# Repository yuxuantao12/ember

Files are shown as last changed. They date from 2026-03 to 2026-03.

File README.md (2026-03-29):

# EMBER — Emergency Monitor for Building Evacuation and Rescue

> Real-time firefighter tracking system for incident commanders. Built for a 24-hour hackathon.





## What is EMBER?

EMBER tracks firefighters inside buildings in real time. Each firefighter wears a sensor node that broadcasts their GPS position and heading via NRF24L01 radio to a base station outside the building. The base station forwards data over USB serial to a laptop running a browser-based dashboard that overlays firefighter positions on an uploaded floor plan.

```
┌─────────────┐     ┌─────────────┐
│ Wearable A  │     │ Wearable B  │
│ Nano+GPS+IMU│     │ Nano+GPS+IMU│
└──────┬──────┘     └──────┬──────┘
       │  2.4 GHz Radio    │
       └────────┬──────────┘
                │
       ┌────────┴────────┐
       │  Base Station   │
       │  Nano+NRF24L01  │
       └────────┬────────┘
                │ USB Serial
       ┌────────┴────────┐
       │ Laptop Dashboard│
       │ Chrome/Edge     │
       └─────────────────┘
```

## Project Structure

```
ember/
├── dashboard/              # Browser-based tracking dashboard (CS person)
│   ├── index.html          # Main entry point — open in Chrome
│   ├── css/
│   │   └── styles.css      # All styles — dark fire-themed UI
│   └── js/
│       ├── app.js           # Init, state management, UI updates
│       ├── serial.js        # Web Serial API connection layer
│       ├── canvas.js        # Floor plan rendering + firefighter markers
│       ├── calibration.js   # GPS-to-pixel coordinate mapping
│       └── mock.js          # Fake data generator for development
│
├── firmware/               # Arduino sketches (CE person)
│   ├── wearable_node/      # Wearable firefighter node firmware
│   │   └── wearable_node.ino
│   ├── base_station/       # Base station receiver firmware
│   │   └── base_station.ino
│   └── esp01_wifi_bonus/   # BONUS: ESP-01 WiFi dashboard
│       └── esp01_wifi_bonus.ino
│
├── hardware/               # Wiring diagrams and pin maps (EE person)
│   └── PIN_MAP.md          # Complete pin assignments for all units
│
├── docs/                   # Build guide and documentation
│   └── EMBER_Nano_Build_Guide.docx
│
└── README.md               # This file
```

## Hardware Requirements

| Component | Qty | Purpose |
|---|-----|---|
| Arduino Nano | 3 | Main controller for all units |
| NRF24L01 (standard) | 3 | 2.4 GHz radio (1 per Nano) |
| IMU (MPU6050/9250) | 2 | Heading/orientation (wearables only) |
| GPS (NEO-6M) | 2 | Position tracking (wearables only) |
| Active Buzzer | 3 | Audible alerts (1 per unit) |
| 10µF Capacitor | 3 | NRF24L01 power stabilization |
| ESP-01 (ESP8266) | 1 | BONUS: WiFi phone dashboard |

## Quick Start

### Dashboard (no hardware needed)
1. Open `dashboard/index.html` in **Chrome** or **Edge**
2. Click **Mock Data** to simulate two firefighters
3. Click **Upload Floor Plan** to load a building image
4. Click **Calibrate** to set GPS-to-pixel mapping

### With Hardware
1. Flash `firmware/wearable_node/wearable_node.ino` to wearable Nanos
2. Flash `firmware/base_station/base_station.ino` to base station Nano
3. Connect base station to laptop via USB
4. Open `dashboard/index.html` in Chrome
5. Click **Connect** and select the Nano's serial port

## Pin Map (Arduino Nano)

| Pin | Wearable | Base Station |
|-----|---|---|
| D3 | GPS TX (SoftwareSerial RX) | ESP-01 RX (bonus) |
| D4 | GPS RX (SoftwareSerial TX) | — |
| D6 | Buzzer + | Buzzer + |
| D9 | NRF24L01 CE | NRF24L01 CE |
| D10 | NRF24L01 CSN | NRF24L01 CSN |
| D11 | NRF24L01 MOSI | NRF24L01 MOSI |
| D12 | NRF24L01 MISO | NRF24L01 MISO |
| D13 | NRF24L01 SCK | NRF24L01 SCK |
| A4 | IMU SDA | — |
| A5 | IMU SCL | — |
| 3.3V | NRF24L01 VCC | NRF24L01 VCC |
| 5V | IMU VCC, GPS VCC | — |

## Serial Protocol

Base station sends JSON lines at 115200 baud:
```json
{"id":1,"lat":29.6516,"lng":-82.3248,"heading":135.2,"fix":1,"alert":0,"batt":87,"stat":0}
```

Dashboard can send commands back:
```
BUZZ:1    // Alert firefighter 1
BUZZ:2    // Alert firefighter 2
```

## Team Roles

- **EE** — Soldering, wiring, 3D enclosures, hardware debugging
- **CE** — All Arduino firmware, radio config, serial protocols
- **CS** — Browser dashboard, Web Serial API, UI/UX

## Browser Support

The dashboard uses the [Web Serial API](https://developer.mozilla.org/en-US/docs/Web/API/Web_Serial_API) which is supported in:
- ✅ Chrome 89+
- ✅ Edge 89+
- ❌ Firefox (not supported)
- ❌ Safari (not supported)

## Google Maps API Key

The private API key has been omitted. Please request an API key at https://console.cloud.google.com/ for map function. 

## License

MIT

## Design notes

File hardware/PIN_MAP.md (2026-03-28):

# EMBER Hardware Pin Map — Arduino Nano

## Wearable Node (×2)

| Nano Pin | Connected To | Protocol | Wire Color (suggested) |
|---|---|---|---|
| D0 (RX)  | USB (reserved) | Hardware UART | — do not connect — |
| D1 (TX)  | USB (reserved) | Hardware UART | — do not connect — |
| D2 | *unassigned* | — | |
| D3 | GPS TX | SoftwareSerial RX | White |
| D4 | GPS RX | SoftwareSerial TX | Gray |
| D5 | *unassigned* | — | |
| D6 | Buzzer (+) | Digital Output | Yellow |
| D7 | *unassigned* | — | |
| D8 | *unassigned* | — | |
| D9 | NRF24L01 CE | Digital Output | Orange |
| D10 | NRF24L01 CSN | SPI SS | Brown |
| D11 | NRF24L01 MOSI | SPI MOSI | Green |
| D12 | NRF24L01 MISO | SPI MISO | Blue |
| D13 | NRF24L01 SCK | SPI SCK | Purple |
| A0–A3 | *unassigned* | — | |
| A4 | IMU SDA | I2C Data | White (twisted pair) |
| A5 | IMU SCL | I2C Clock | Yellow (twisted pair)  |
| A6–A7 | *unassigned* | Analog only | |
| 5V | IMU VCC, GPS VCC | Power | Red |
| 3.3V | NRF24L01 VCC + Cap | Power | Red (3.3V rail) |
| GND | All GNDs + Cap − | Ground | Black |

**Critical:** 10µF capacitor across NRF24L01 VCC and GND, as close to the module as possible.

---

## Base Station (×1)

| Nano Pin | Connected To | Protocol | Notes |
|---|---|---|---|
| D0 (TX)  | USB → Laptop | Hardware UART | JSON data at 115200 |
| D1 (RX)  | USB ← Laptop | Hardware UART | BUZZ commands from dashboard |
| D3 | ESP-01 RX (BONUS)  | SoftwareSerial TX | Via voltage divider (1K+2K) |
| D6 | Buzzer (+) | Digital Output | |
| D9 | NRF24L01 CE | Digital Output | |
| D10 | NRF24L01 CSN | SPI SS | |
| D11 | NRF24L01 MOSI | SPI MOSI | |
| D12 | NRF24L01 MISO | SPI MISO | |
| D13 | NRF24L01 SCK | SPI SCK | |
| 3.3V | NRF24L01 VCC + Cap (+ ESP-01 VCC if bonus) | Power | |
| GND | All GNDs | Ground | |

---

## ESP-01 Bonus (base station only)

| ESP-01 Pin | Connected To | Notes |
|---|---|---|
| VCC | Nano 3.3V | 3.3V ONLY |
| GND | Nano GND | |
| RX | Nano D3 via voltage divider | 1K from D3 → ESP RX, 2K from ESP RX → GND |
| TX | Not connected | |
| CH_PD (EN) | 3.3V via 10K pullup | Must be HIGH to run |
| GPIO0 | 3.3V via 10K pullup | HIGH = run mode, LOW = flash mode  |
| GPIO2 | Not connected | |
| RST | 3.3V via 10K pullup | Prevent accidental resets |

---

## NRF24L01 Module Pinout (8 pins, top view)

```
         ┌─────────────┐
    GND  │ 1    2      │  VCC (3.3V!)
     CE  │ 3    4      │  CSN
    SCK  │ 5    6      │  MOSI
   MISO  │ 7    8      │  IRQ (not used)
         └─────────────┘
```

**Pin 2 (VCC) = 3.3V ONLY. Connecting to 5V will permanently destroy the module.**

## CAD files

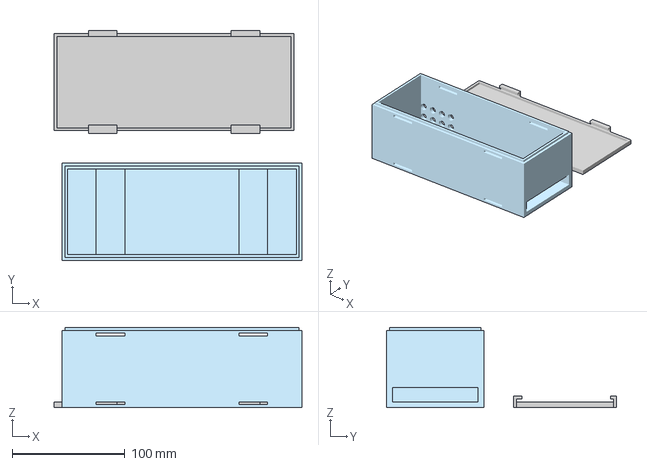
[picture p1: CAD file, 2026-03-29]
Design.3mf
220.4 x 204.2 x 71.1 mm

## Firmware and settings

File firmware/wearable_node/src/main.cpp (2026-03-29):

#include <SPI.h>
#include <RF24.h>
#include <TinyGPSPlus.h>
#include <SoftwareSerial.h>
#include <Wire.h>
#include <avr/wdt.h>

// Unique ID for this specific unit so the base station knows who is talking
#define NODE_ID      1
#define RF_CHANNEL   108
#define TX_INTERVAL  500
#define BUZZER_PIN   6
#define GPS_RX_PIN   3
#define GPS_TX_PIN   4
#define NRF_CE_PIN   9
#define NRF_CSN_PIN  10
#define IMU_ADDR     0x68

// Button pins
#define BTN_SURVIVOR   2   // "Survivor Here"
#define BTN_NO_SURVIVOR 5  // "No Survivor"
#define BTN_DANGER     7   // "Dangerous Area"

// Alert enums
#define ALERT_NONE        0
#define ALERT_STATIONARY  1  
#define ALERT_SURVIVOR    2   // survivor found here
#define ALERT_NO_SURVIVOR 3   // no survivor here
#define ALERT_DANGER      4   // dangerous area

const byte pipeAddr[] = "EMBB1";

//Base/Node struct
struct __attribute__((packed)) SensorPacket {
  uint8_t  nodeId;
  float    latitude;
  float    longitude;
  float    heading;
  uint8_t  gpsFix;
  uint8_t  alertFlag;
  uint8_t  batteryPct;
  uint16_t stationaryMs;
  float    drLat;
  float    drLng;
  uint8_t  pinDrop;
};

RF24 radio(NRF_CE_PIN, NRF_CSN_PIN);
TinyGPSPlus gps;
SoftwareSerial gpsSerial(GPS_RX_PIN, GPS_TX_PIN);

SensorPacket packet;
unsigned long lastTx     = 0;
unsigned long lastMoveTime = 0;
float prevHeading        = 0;

//Dead reckoning state
float    drLat           = 0.0;   // current DR latitude
float    drLng           = 0.0;   // current DR longitude
bool     drInitialised   = false;
float    drSpeed         = 0.9;  
unsigned long lastDrUpdate = 0;

//Button debounce state
unsigned long lastBtnPress[3] = {0, 0, 0};
const uint8_t btnPins[3]      = {BTN_SURVIVOR, BTN_NO_SURVIVOR, BTN_DANGER};
const uint8_t btnAlerts[3]    = {ALERT_SURVIVOR, ALERT_NO_SURVIVOR, ALERT_DANGER};
const uint16_t DEBOUNCE_MS    = 300;

// Pending pin drop
bool    pendingPin     = false;
uint8_t pendingAlert   = ALERT_NONE;
float   pendingDrLat   = 0.0;
float   pendingDrLng   = 0.0;

float readHeading();
void  updateDeadReckoning();
void  checkButtons();
void  buzzerConfirm(uint8_t alertType);

void setup() {
  wdt_disable();
  Serial.begin(115200);
  Serial.println(F("Node A starting..."));

  // Button pins — internal pull-up, buttons connect pin to GND
  pinMode(BTN_SURVIVOR,    INPUT_PULLUP);
  pinMode(BTN_NO_SURVIVOR, INPUT_PULLUP);
  pinMode(BTN_DANGER,      INPUT_PULLUP);

  pinMode(BUZZER_PIN, OUTPUT);
  digitalWrite(BUZZER_PIN, HIGH);
  delay(150);
  digitalWrite(BUZZER_PIN, LOW);

  gpsSerial.begin(9600);

  Wire.begin();
  Wire.beginTransmission(IMU_ADDR);
  Wire.write(0x6B);
  Wire.write(0x00);
  Wire.endTransmission(true);

  if (!radio.begin()) {
    Serial.println(F("NRF FAIL"));
    while (1) {
      digitalWrite(BUZZER_PIN, HIGH); delay(200);
      digitalWrite(BUZZER_PIN, LOW);  delay(200);
    }
  }

  radio.setChannel(RF_CHANNEL);
  radio.setDataRate(RF24_250KBPS);
  radio.setPALevel(RF24_PA_MAX);
  radio.setRetries(15, 15);
  radio.setPayloadSize(sizeof(SensorPacket));
  radio.openWritingPipe(pipeAddr);
  radio.stopListening();

  Serial.println(F("Node A ready."));
  packet.nodeId = NODE_ID;
  lastMoveTime  = millis();
  lastDrUpdate  = millis();
  wdt_enable(WDTO_2S);
}

void loop() {
  wdt_reset();

  // Feed GPS
  while (gpsSerial.available() > 0) gps.encode(gpsSerial.read());

  if (gps.location.isValid()) {
    packet.latitude  = gps.location.lat();
    packet.longitude = gps.location.lng();
    packet.gpsFix    = 1;
    // Use real GPS as DR anchor
    drLat          = packet.latitude;
    drLng          = packet.longitude;
    drInitialised  = true;
  } else {
    packet.latitude  = 0.0;
    packet.longitude = 0.0;
    packet.gpsFix    = 0;
  }

  packet.heading = readHeading();
  updateDeadReckoning();
  checkButtons();

  // Stationary detection
  if (abs(packet.heading - prevHeading) > 5.0) {
    lastMoveTime = millis();
    prevHeading  = packet.heading;
  }
  packet.stationaryMs = (uint16_t)min((unsigned long)65535, millis() - lastMoveTime);

  // Alert priority: button press overrides stationary alert
  if (pendingPin) {
    packet.alertFlag  = pendingAlert;
    packet.drLat      = pendingDrLat;
    packet.drLng      = pendingDrLng;
    packet.pinDrop    = 1;
  } else {
    packet.alertFlag  = (packet.stationaryMs > 60000) ? ALERT_STATIONARY : ALERT_NONE;
    packet.drLat      = drLat;
    packet.drLng      = drLng;
    packet.pinDrop    = 0;
  }

  packet.batteryPct = 100;

  if (millis() - lastTx >= TX_INTERVAL) {
    lastTx = millis();
    bool ok = radio.write(&packet, sizeof(packet));

    // If pin drop was sent, clear it
    if (pendingPin && ok) {
      pendingPin = false;
    }

    // Serial output as JSON for the  dashboard
    Serial.print(F("{\"id\":"));    Serial.print(packet.nodeId);
    Serial.print(F(",\"lat\":"));   Serial.print(packet.latitude, 6);
    Serial.print(F(",\"lng\":"));   Serial.print(packet.longitude, 6);
    Serial.print(F(",\"heading\":")); Serial.print(packet.heading, 1);
    Serial.print(F(",\"fix\":"));   Serial.print(packet.gpsFix);
    Serial.print(F(",\"alert\":")); Serial.print(packet.alertFlag);
    Serial.print(F(",\"batt\":"));  Serial.print(packet.batteryPct);
    Serial.print(F(",\"stat\":"));  Serial.print(packet.stationaryMs);
    Serial.print(F(",\"pin\":"));   Serial.print(packet.pinDrop);
    Serial.print(F(",\"drLat\":")); Serial.print(packet.drLat, 6);
    Serial.print(F(",\"drLng\":")); Serial.print(packet.drLng, 6);
    Serial.println(F("}"));
  }
}

//Dead reckoning update
// Converts heading + speed + elapsed time into a lat/lng offset
void updateDeadReckoning() {
  if (!drInitialised) return;

  unsigned long now = millis();
  float dt = (now - lastDrUpdate) / 1000.0;
  lastDrUpdate = now;

  if (dt <= 0 || dt > 2.0) return;

  // Only advance DR if unit is not stationary
  if (packet.stationaryMs > 3000) return;

  float distMetres = drSpeed * dt;

  // Convert heading to radians
  float headRad = packet.heading * PI / 180.0;

  // 1 degree latitude ≈ 111320 metres
  float dLat = (distMetres * cos(headRad)) / 111320.0;

  // 1 degree longitude ≈ 111320 * cos(lat) metres
  float cosLat = cos(drLat * PI / 180.0);
  float dLng = (cosLat > 0.001) ? (distMetres * sin(headRad)) / (111320.0 * cosLat) : 0.0;

  drLat += dLat;
  drLng += dLng;
}

//Button check with debounce
void checkButtons() {
  for (int i = 0; i < 3; i++) {
    // Buttons are INPUT_PULLUP so LOW = pressed
    if (digitalRead(btnPins[i]) == LOW) {
      unsigned long now = millis();
      if (now - lastBtnPress[i] > DEBOUNCE_MS) {
        lastBtnPress[i] = now;

        // Capture current DR position as pin drop location
        pendingPin     = true;
        pendingAlert   = btnAlerts[i];
        pendingDrLat   = drLat;
        pendingDrLng   = drLng;

         switch (btnAlerts[i]) {
          case ALERT_SURVIVOR:    Serial.println(F(">>> BUTTON: SURVIVOR HERE <<<")); break;
          case ALERT_NO_SURVIVOR: Serial.println(F(">>> BUTTON: NO SURVIVOR <<<")); break;
          case ALERT_DANGER:      Serial.println(F(">>> BUTTON: DANGEROUS AREA <<<")); break;
        }

        buzzerConfirm(btnAlerts[i]);

        Serial.print(F("BTN: alert="));
        Serial.print(btnAlerts[i]);
        Serial.print(F(" drLat="));
        Serial.print(drLat, 6);
        Serial.print(F(" drLng="));
        Serial.println(drLng, 6);
      }
    }
  }
}


void buzzerConfirm(uint8_t alertType) {
  wdt_reset();
  delay(10);  
  switch (alertType) {
    case ALERT_SURVIVOR:
      digitalWrite(BUZZER_PIN, HIGH); delay(80);
      digitalWrite(BUZZER_PIN, LOW);  delay(60);
      digitalWrite(BUZZER_PIN, HIGH); delay(80);
      digitalWrite(BUZZER_PIN, LOW);
      break;
    case ALERT_NO_SURVIVOR:
      digitalWrite(BUZZER_PIN, HIGH); delay(150);
      digitalWrite(BUZZER_PIN, LOW);
      break;
    case ALERT_DANGER:
      for (int i = 0; i < 3; i++) {
        digitalWrite(BUZZER_PIN, HIGH); delay(60);
        digitalWrite(BUZZER_PIN, LOW);  delay(50);
      }
      break;
  }
  wdt_reset();
}

float readHeading() {
  Wire.beginTransmission(IMU_ADDR);
  Wire.write(0x47);
  Wire.endTransmission(false);
  Wire.requestFrom(IMU_ADDR, 2, true);
  int16_t gyroZ = Wire.read() << 8 | Wire.read();
  float rate = gyroZ / 131.0;

  static float yaw = 0;
  static unsigned long lastTime = 0;
  unsigned long now = millis();
  float dt = (now - lastTime) / 1000.0;
  lastTime = now;
  if (dt > 0 && dt < 1.0) yaw += rate * dt;
  yaw = fmod(yaw, 360.0);
  if (yaw < 0) yaw += 360.0;
  return yaw;
}

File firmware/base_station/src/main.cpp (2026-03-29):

#include <SPI.h>
#include <RF24.h>
#include <avr/wdt.h>

// Using channel 108 to stay clear of the noisier low-end WiFi frequencies
#define RF_CHANNEL   108
#define NRF_CE_PIN   9
#define NRF_CSN_PIN  10
#define BUZZER_PIN   6

// This struct is the "handshake" between the nodes and this base station.
// __attribute__((packed)) ensures no sneaky padding is added by the compiler,
// so the bytes align perfectly over the air.

struct __attribute__((packed)) SensorPacket {
  uint8_t  nodeId;
  float    latitude;
  float    longitude;
  float    heading;
  uint8_t  gpsFix;
  uint8_t  alertFlag;
  uint8_t  batteryPct;
  uint16_t stationaryMs;
  float    drLat;
  float    drLng;
  uint8_t  pinDrop;
};

RF24 radio(NRF_CE_PIN, NRF_CSN_PIN);

// Hardcoded addresses for our two main nodes (only one node implemented)
const byte addrA[] = "EMBB1";
const byte addrB[] = "EMBB2";

unsigned long lastPacketTime[3] = {0, 0, 0};
bool buzzerActive = false;
unsigned long buzzerOffTime = 0;

// Prototypes for the helpers below
String buildJson(SensorPacket &p);
void sendBuzzCommand(uint8_t targetId);

void setup() {
  wdt_disable();
  Serial.begin(115200);
  Serial.println(F("{\"status\":\"EMBER base station starting\"}"));

  pinMode(BUZZER_PIN, OUTPUT);
  digitalWrite(BUZZER_PIN, HIGH);
  delay(100);
  digitalWrite(BUZZER_PIN, LOW);

  if (!radio.begin()) {
    Serial.println(F("{\"error\":\"NRF HARDWARE FAIL\"}"));
    while (1) {
      digitalWrite(BUZZER_PIN, HIGH); delay(200);
      digitalWrite(BUZZER_PIN, LOW);  delay(200);
    }
  }

// Radio fine-tuning: 250KBPS gives us the best possible range
  radio.setChannel(RF_CHANNEL);
  radio.setDataRate(RF24_250KBPS);
  radio.setPALevel(RF24_PA_MAX);
  radio.setRetries(15, 15);
  radio.setPayloadSize(sizeof(SensorPacket));

// Listen for both nodes simultaneously on different pipes
  radio.openReadingPipe(1, addrA);
  radio.openReadingPipe(2, addrB);
  radio.startListening();

  Serial.println(F("{\"status\":\"Listening on EMBB1 and EMBB2\"}"));
  wdt_enable(WDTO_2S);
}

void loop() {
  wdt_reset();
  uint8_t pipeNum = 0;

// Check if any node has sent a status update
  if (radio.available(&pipeNum)) {
    SensorPacket pkt;
    radio.read(&pkt, sizeof(pkt));

// We use the pipe number as the ID to verify which node sent what
    pkt.nodeId = pipeNum;
    lastPacketTime[pkt.nodeId] = millis();
    Serial.println(buildJson(pkt));

  }

  if (Serial.available()) {
    String cmd = Serial.readStringUntil('\n');
    cmd.trim();
    if (cmd.startsWith("BUZZ:")) {
      uint8_t targetId = cmd.charAt(5) - '0';
      if (targetId == 1 || targetId == 2) {
        sendBuzzCommand(targetId);
        Serial.print(F("{\"ack\":\"BUZZ sent to node "));
        Serial.print(targetId);
        Serial.println(F("\"}"));
      }
    }
  }

  if (buzzerActive) {
    digitalWrite(BUZZER_PIN, (millis() / 300) % 2 == 0 ? HIGH : LOW);
    if (millis() > buzzerOffTime) {
      buzzerActive = false;
      digitalWrite(BUZZER_PIN, LOW);
    }
  }
}

// Converts the raw struct into a JSON string for easy parsing by external software
String buildJson(SensorPacket &p) {
  //Alert name
  const char* alertName;
  switch (p.alertFlag) {
    case 0:  alertName = "null";    break;
    case 1:  alertName = "stationary";   break;
    case 2:  alertName = "survivor";     break;
    case 3:  alertName = "no_survivor";  break;
    case 4:  alertName = "danger";       break;
    default: alertName = "unknown";      break;
  }

  String s = "{\"id\":";
  s += p.nodeId;
  s += ",\"lat\":";      s += String(p.latitude,  6);
  s += ",\"lng\":";      s += String(p.longitude, 6);
  s += ",\"heading\":";  s += String(p.heading,   1);
  s += ",\"fix\":";      s += p.gpsFix;
  s += ",\"alert\":";    s += p.alertFlag;
  s += ",\"alertName\":\""; s += alertName; s += "\"";
  s += ",\"batt\":";     s += p.batteryPct;
  s += ",\"stat\":";     s += p.stationaryMs;
  s += ",\"pin\":";      s += p.pinDrop;
  s += ",\"drLat\":";    s += String(p.drLat, 6);
  s += ",\"drLng\":";    s += String(p.drLng, 6);
  s += "}";
  return s;
}

// Switches from "Listening" to "Talking" mode to send a command back to a node
void sendBuzzCommand(uint8_t targetId) {
  radio.stopListening();
  const byte* addr = (targetId == 1) ? addrA : addrB;
  radio.openWritingPipe(addr);
  uint8_t cmd = 0xFF;
  radio.write(&cmd, 1);

// Return to listening mode so we don't miss the next update
  radio.openReadingPipe(1, addrA);
  radio.openReadingPipe(2, addrB);
  radio.startListening();
}
